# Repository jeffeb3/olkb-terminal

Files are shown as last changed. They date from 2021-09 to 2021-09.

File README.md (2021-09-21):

# OLKB-Terminal

Terminal with builtin ortholinear keyboard and touch screen as a home automation interface.

## Features

- Step and STLs available for non-commercial use.
- 7" Touch Screen
- Raspberry pi 4
- Home assistant loads in kiosk mode.
- 5x1 buttons to interact directly with home assistant with physical buttons
 
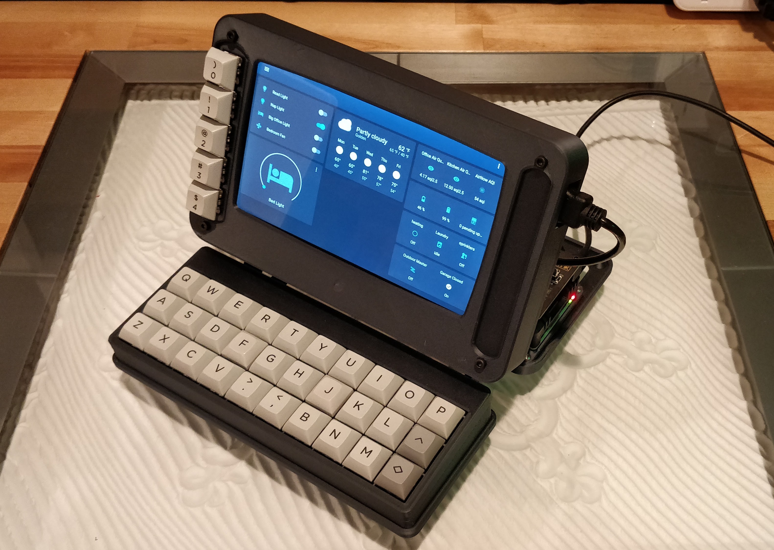
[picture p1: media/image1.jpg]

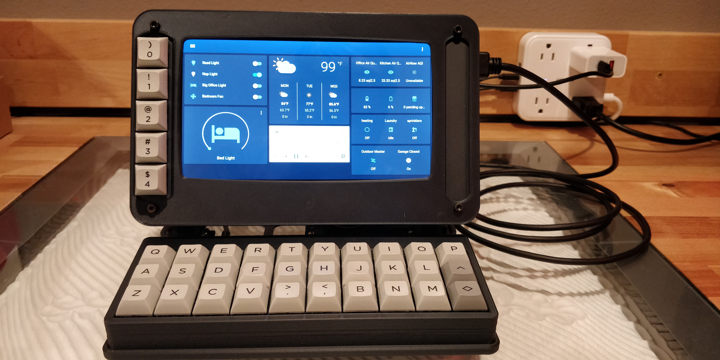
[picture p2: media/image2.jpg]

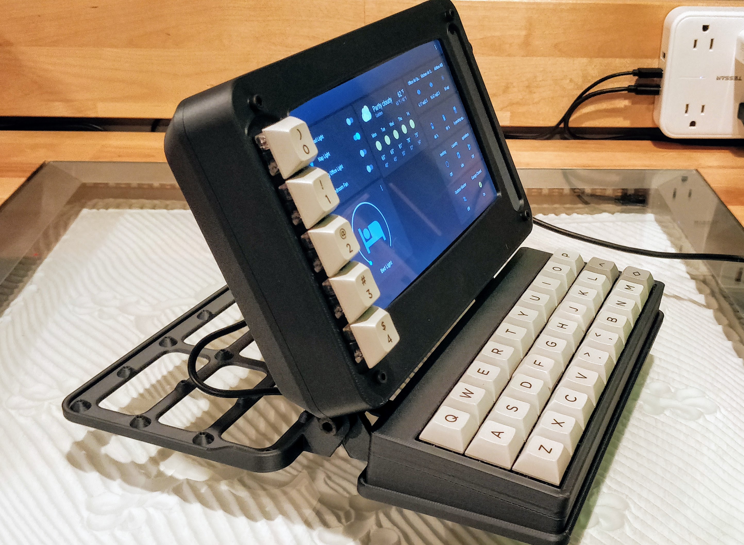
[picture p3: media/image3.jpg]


- Customizable panels for the front, 3 in the back and a grid for custom attachments.

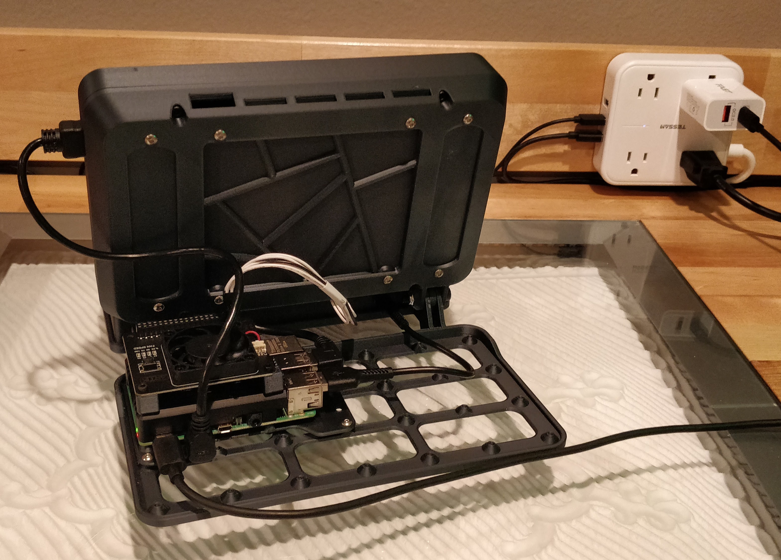
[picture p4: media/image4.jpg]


- [Void30 ortho linear key board](https://github.com/victorlucachi/void30) running qmk open source firmware.

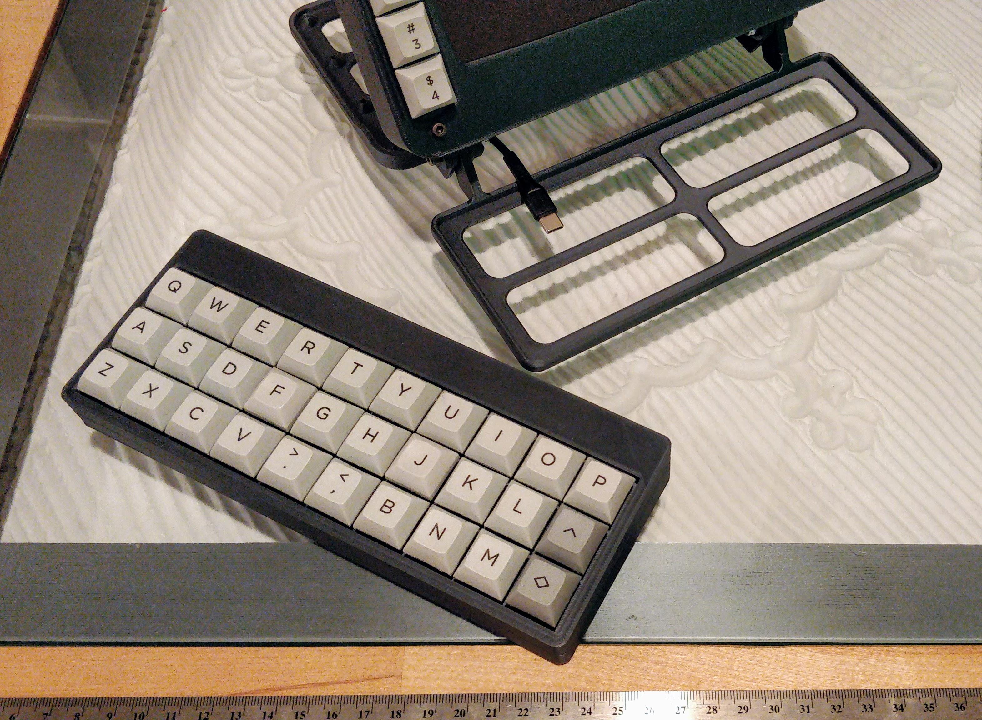
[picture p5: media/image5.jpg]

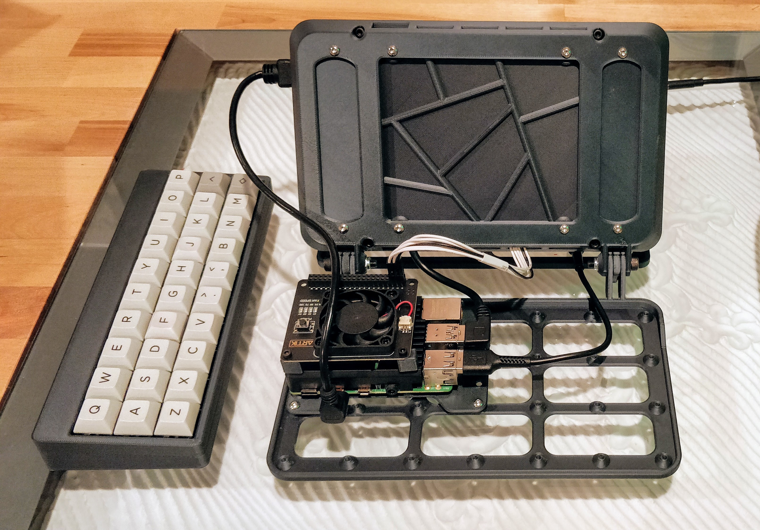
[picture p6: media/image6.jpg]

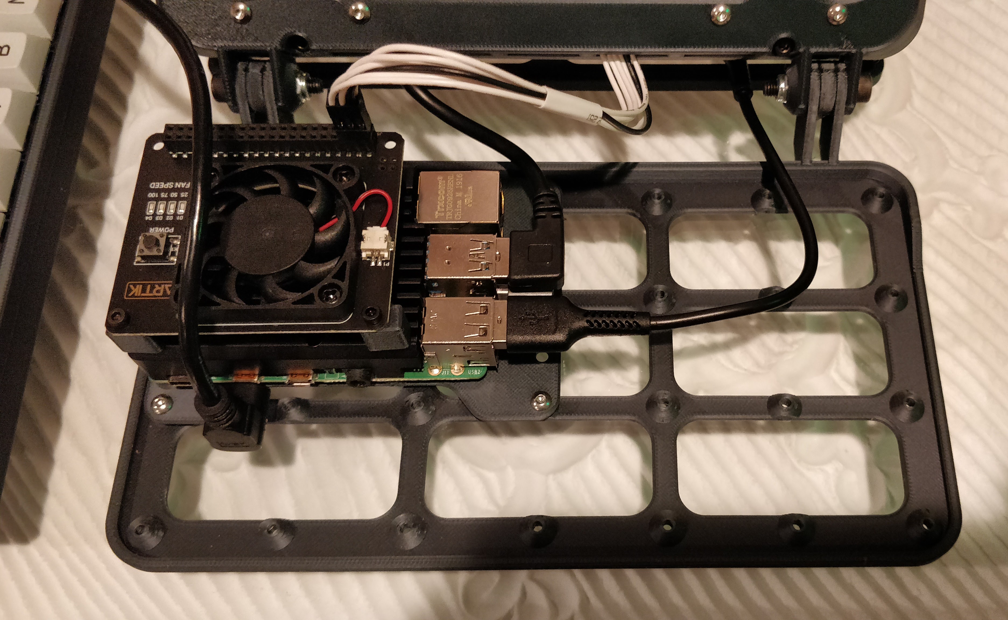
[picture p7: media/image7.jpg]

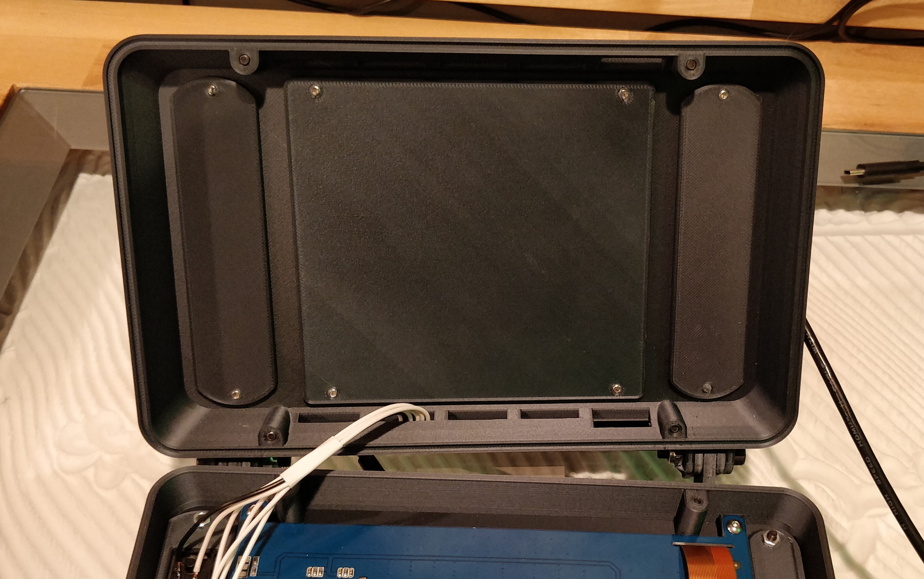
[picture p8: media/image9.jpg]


## Bill of Materials (BOM)

Note: I chose these because I mostly already had them. There are many other choices available. Some
will be less expensive and some will work better. Some will just be different, but you might prefer
them. That's all part of the fun.

### Printed Parts

I used the [Ziro Carbon Fiber PLA Filament](https://amzn.to/39prwRQ).

| Part Name | Qty  | X size (mm) | Y size (mm) | STL |
| --- | ---- | --- | --- | ----- |
| Screen Front | 1 | 214 | 133 | [STL](models/stl/ScreenFrontV1.stl) |
| Screen Rear | 1 | 214 | 133 | [STL](models/stl/ScreenRearV1.stl) |
| Void30 Base Plate | 1 | 207 | 111 | [STL](models/stl/Void30BasePlateV1.stl) |
| Rear Base Plate | 1 | 211 | 139 | [STL](models/stl/RearBasePlateV1.stl) |
| Pi Plate | 1 | 106 | 74 | [STL](models/stl/PiPlateV1.stl) |
| 5x1 Front Acc Panel | 1 | 119 | 22 | [STL](models/stl/5x1FrontAccPanelV1.stl) |
| Small Front Acc Blank Panel | 1 | 120 | 16 | [STL](models/stl/SmallFrontAccBlankPanelV1.stl) |
| Rear Large Blank Panel | 1 | 116 | 107 | [STL](models/stl/RearLargeBlankPanelV1.stl) |
| Rear Small Blank Panel | 2 | 107 | 27 | [STL](models/stl/RearSmallBlankPanelV1.stl) |
| Fan Holder (optional) | 2 | 10 | 10 | [STL](models/stl/FanHolderV1.stl) |

These parts are licensed CC-BY-NC. That means you can't charge for them, and you can't send .stl
to a shop that charges for prints.

I have designed these to be as easy to print as possible, but if you really want to buy a printed
set, contact me and I'll see what solutions we can find.

### Raspberry Pi Components

| Name | Link |
| ----- | ---- |
| Screen (C) [1] | https://amzn.to/3ztpCKe |
| Raspberry Pi 4 2GB | https://amzn.to/3nM6MMq |
| SD Card [2] | https://amzn.to/3Cx8bug |
| USB Drive [2] | https://amzn.to/3EDvPaz |
| Power Supply | https://amzn.to/2XvkFU4 |
| Power Cable (USB-C on both ends) | https://amzn.to/3lLiLae |
| Case | https://amzn.to/3kqMV3l |
| Fan | https://amzn.to/39kYTVV |

[1] I have this version, which is more than a year old now. There is a newer version of the screen that looks like it has some nice features:
   - Screen IPS (H) version: https://amzn.to/3hPevp4
   
[2] I use a USB Drive to run the pi. If you do that too, you can just use any 8GB+ micro SD card to
get the raspberry pi booted, and then use the USB drive from then on.

### Void30

Take a look at the [victorlucachi/void30](https://github.com/victorlucachi/void30) repo for details.

I used an
[Elite-C](https://keeb.io/products/elite-c-low-profile-version-usb-c-pro-micro-replacement-atmega32u4)
microcontroller, which is essentially an Arduino Pro Micro with a USB-C port.

### Cables

| Name | Link |
| ----- | ---- |
| Micro HDMI Video Cable | https://amzn.to/3tWw2QZ |
| Micro USB Right Angle Touch Screen Cable | https://amzn.to/39kEMXI |
| USB-C for Void30 (If you have a USB-C) | https://amzn.to/3lLH9IQ |
| Power Cable (USB-C on both ends) | https://amzn.to/3lLiLae |

Make sure you get the right cable for your Void30 microcontroller. You need one that is about 6inches (15cm).

### Screws

| Location | Size | Min. Qty |
| --- | --- | --- |
| Hinge | M5x15mm+ | 2 |
| Hinge | M5 Lockhnut | 2 |
| Screen Case | M4x14mm-20mm | 4 |
| Accessory Mounts | M3x6mm | 18+ |

### 5x1 Front Switch Panel

You should have enough leftovers from the Void30 build. Except for the Dupont connectors.

- Wires, 24awg-28awg should be fine. I would guess the farthest one is less than 8" (20cm) long.
- 5x cherry mx compatible switches
- 5x cherry mx compatible keycaps, but I hope to release some STLs for printable ones soon.
- 2x3 Dupont connector. If you aren't already prepared to crimp dupont connectors, I would try to
  find a 2x3 dupont cable and just cut off the other end to solder.
- Heat shrink. Optional, but makes these wires a little more tidy.

## Scripts/Setup

I have a very peculiar raspberry pi setup. If this project takes off, I would consider making a custom image for it.
But this can be accomplished with a regular raspian setup.

Until then, these are some of the key parts I used to get the software/OS side working:

1. Home Assistant should already be running (probably on another machine).
2. Change your user password, please.
3. Install chromium browser. Any browser should work ok, but chromium has a kiosk mode.
   - The command I use to launch the browser is: `/usr/bin/chromium-browser --kiosk --noerrdialogs --enable-features=OverlayScrollbar --disable-restore-session-state http://homeassistant:8123`
4. Use `raspi-config` to auto login.
5. Disable screen savers. I do that so I can see what is on the screen without touching it. Run these commands at startup. Check to see if they work with `xset q`:
    `xset s noblank`
    `xset s off`
    `xset -dpms`
6. [Set up the `buttons.py`](buttons/)

## Connected Projects

This project is very dependent on a lot of other open source and hardware projects.

 - [Home Assistant](https://home-assistant.io) let me write a few lines of code and scripts instead of thousands to get a clean interface.
 - [victorlucachi/void30](https://github.com/victorlucachi/void30) made a fun keyboard that is not only a perfect fit, but it inspired some of the design choices in CAD. 
 - [qmk_firmare](https://qmk.fm/) QMK Firmware is the brains of the void30 and is a pleasure to work with.
 - [browser_mod](https://github.com/thomasloven/hass-browser_mod) makes it possible to control the display with home assistant automations.

Of course, raspberry pi, Linux, and a thousand projects related to getting a computer running on a pi are also integral.

# License



This version of this project Has shapes and measurements based off of the Void30 project by @victorlucachi. That project, and
this one are licensed under a [Creative Commons Attribution-NonCommercial 4.0 International License](https://creativecommons.org/licenses/by-nc/4.0/).

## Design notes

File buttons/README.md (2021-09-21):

## 5x1 Button Set Up

This isn't going to be a beginner guide. But I hope it is easy enough to follow. If you are having
trouble, ask me, or ask a friend and we can update these instructions for the next user.

1. Take a look at the [script](olkb-terminal-buttons.py). You might want to look at the documentation for
   [gpiozero.Button](https://gpiozero.readthedocs.io/en/stable/api_input.html#button).
2. The script will check for pins 16, 19, 20, 21, 26 and if any of them connect to ground, it will trigger an automation named:
    `olkb-terminal-button-0`, or any from 1-4.
3. Wire up the buttons.
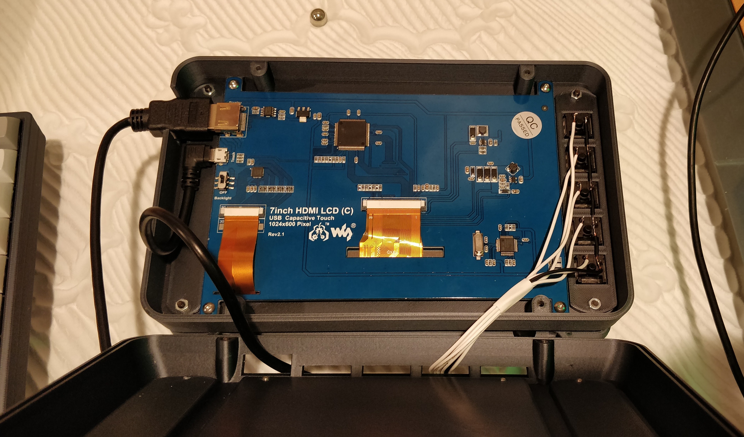
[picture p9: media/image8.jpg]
button wires


I wired all the terminals on the right side of the switches together and tied them to ground. I then
wired each of the other sides of the switches to their own pins at the end of the GPIO on the rpi4.

[Here is a handy pinout](https://pinout.xyz/pinout/pin35_gpio19#)

4. Get the long lived access token for your home assistant setup. This may get out of date, but
   right now, you can click on your account in the HA interface and navigate to the bottom and add a
   long lived access token. Give it a name like, "olkb-terminal" and then past it in the buttons.py
   script.
   
5. Test the script. You should be able to do something like `python3 buttons.py` and then press the
   buttons. You should see messages coming back indicating that buttons were pressed.
   
6. Set up your automations. The script calls automations like `olkb-terminal-button-0`. In HA, have
   them trigger something you can test with. Like a notification, or toggling a light switch.
   
7. Set up `browser_mod` in your Home Assistant. Browser mod is very powerful and is popular enough
   to have a lot of good tutorials on it already. But if you get stuck, this is what one of my
   automations looks like:

```yaml
  alias: olkb-terminal-button-0
  description: What to do when we press a button on the olkb terminal screen
  trigger: []
  condition: []
  action:
  - service: browser_mod.navigate
    data:
      deviceID: <put your deviceID here>
      navigation_path: /lovelace-terminal/0
```

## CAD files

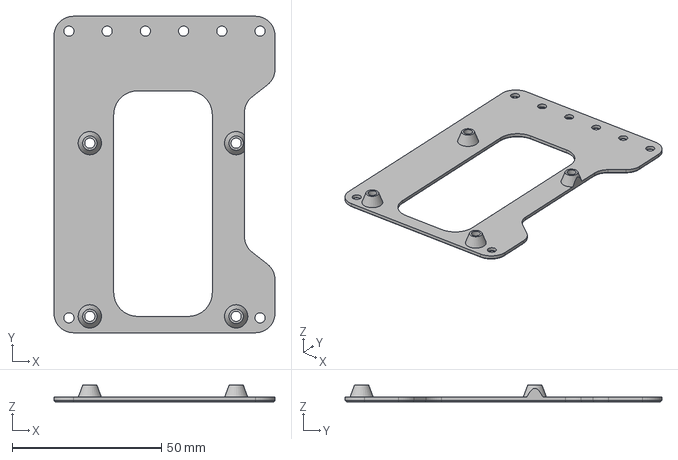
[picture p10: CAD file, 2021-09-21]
models/step/PiPlateV1.step
74.0 x 106.0 x 5.60 mm

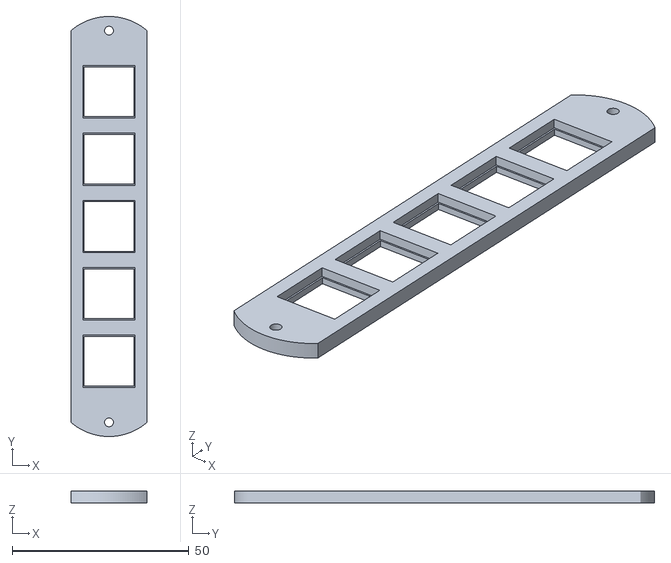
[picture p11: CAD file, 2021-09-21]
models/stl/5x1FrontAccPanelV1.stl
21.5 x 118.7 x 3.40

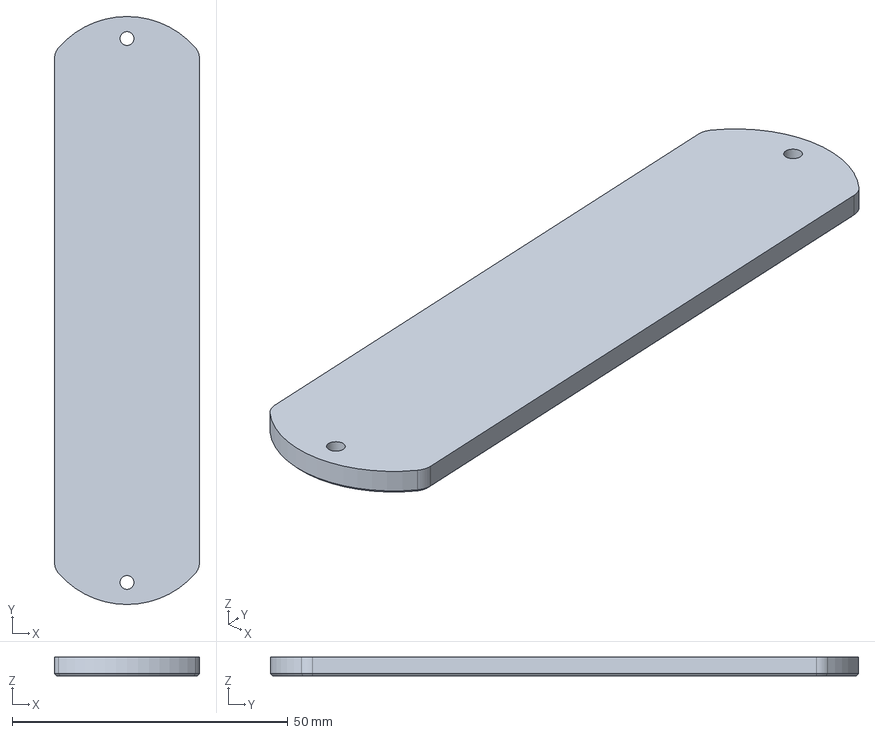
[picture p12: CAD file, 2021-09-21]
models/step/RearSmallBlankPanelV1.step
26.3 x 106.7 x 3.40 mm

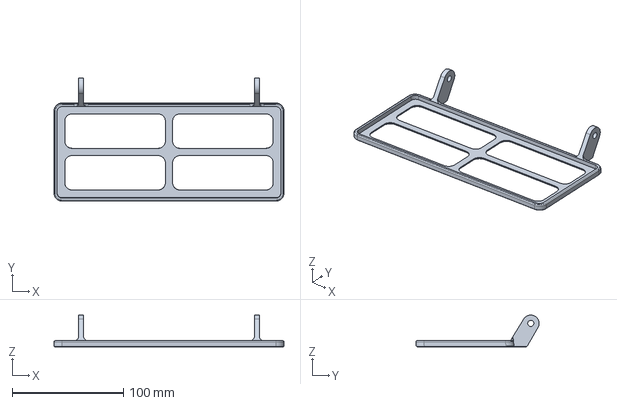
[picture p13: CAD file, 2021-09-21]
models/step/Void30BasePlateV1.step
206.9 x 110.8 x 28.6 mm

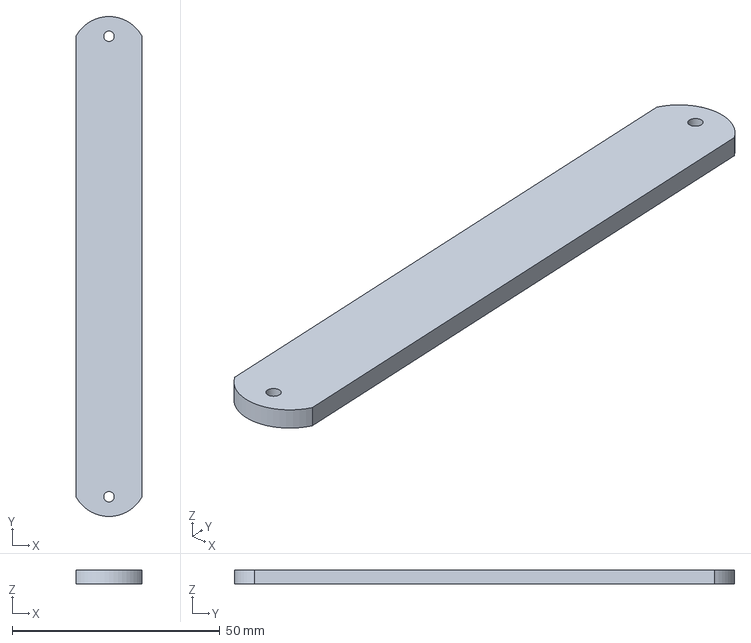
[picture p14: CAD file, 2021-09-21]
models/step/SmallFrontAccBlankPanelV1.step
15.9 x 120.2 x 3.40 mm

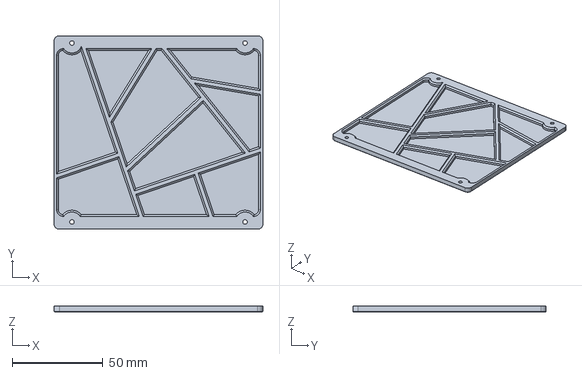
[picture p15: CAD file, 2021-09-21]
models/step/RearLargeBlankPanelV1.step
115.2 x 106.6 x 3.40 mm

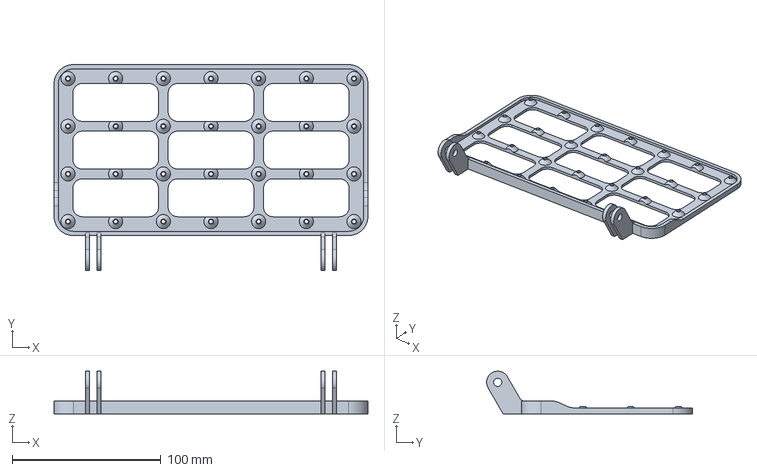
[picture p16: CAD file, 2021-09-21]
models/step/RearBasePlateV1.step
210.8 x 138.2 x 28.7 mm

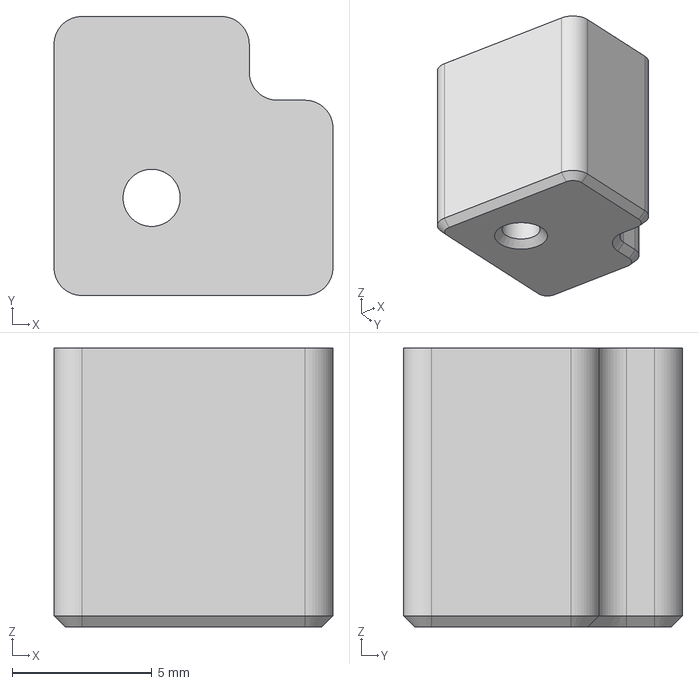
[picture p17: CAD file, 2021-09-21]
models/step/FanHolderV1.step
10.0 x 10.0 x 10.00 mm

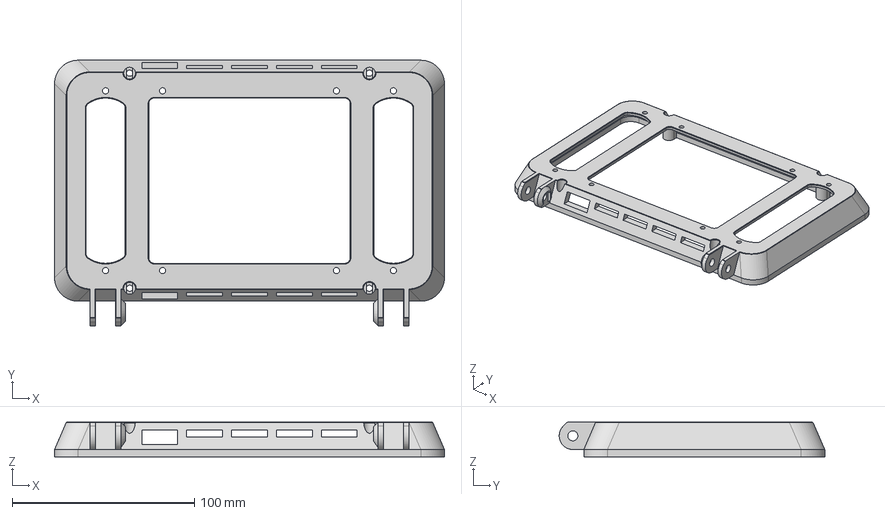
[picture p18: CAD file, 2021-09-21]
models/step/ScreenRearV1.step
214.0 x 145.7 x 19.0 mm

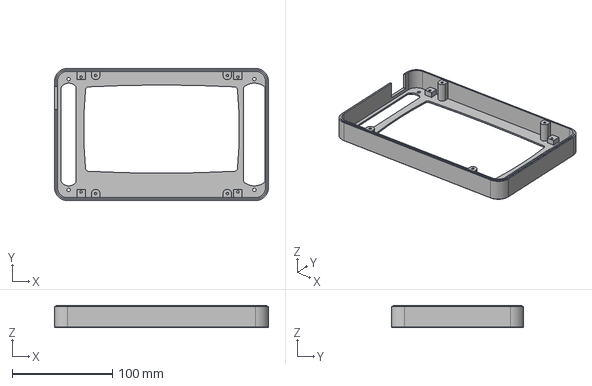
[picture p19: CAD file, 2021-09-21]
models/step/ScreenFrontV1.step
214.0 x 132.2 x 22.2 mm

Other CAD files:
models/step/m5x1FrontAccPanelV1.step
models/stl/FanHolderV1.stl
models/stl/PiPlateV1.stl
models/stl/RearLargeBlankPanelV1.stl
models/stl/RearSmallBlankPanelV1.stl
models/stl/ScreenFrontV1.stl
models/stl/SmallFrontAccBlankPanelV1.stl

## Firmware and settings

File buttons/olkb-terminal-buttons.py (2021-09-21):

#!/usr/bin/python3

from gpiozero import Button
from signal import pause
from os import system
from os import environ

environ['HASS_SERVER']="http://homeassistant:8123"
# see https://www.home-assistant.io/docs/authentication/
environ['HASS_TOKEN']="put your key here"

pins = [19, 26, 21, 20, 16]

buttons = [Button(pin, bounce_time=0.05) for pin in pins]

def button_callback(button):
    if button.pin.number not in pins:
        # How did we get here?
        return

    swtich_number = pins.index(button.pin.number)

    print("Pressed Button {}".format(swtich_number))
    system("hass-cli service call automation.trigger --arguments entity_id=automation.olkb_terminal_button_{}".format(swtich_number))

for button in buttons:
    button.when_pressed = button_callback

pause()

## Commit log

2021-09-21 Added Features and button stub.
2021-09-21 Added button script.
2021-09-21 Added 4 STLs.
    [Screen Front v1.step, Screen Front v1.stl, Screen Rear v1.step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]
2021-09-21 Renamed Screen parts.
    [Screen Front v1.step, Screen Front v1.stl, Screen Rear v1.step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]
2021-09-21 Add the rest of the 3D files for "V1"
    [5x1FrontAccPanelV1.stl, FanHolderV1.step, FanHolderV1.stl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]
